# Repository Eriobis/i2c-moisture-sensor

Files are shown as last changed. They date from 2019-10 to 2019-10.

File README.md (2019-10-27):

# i2c-moisture-sensor
BLE Moisture Sensor
Based on Miceuz's work 
 - I2C based soil moisture sensor. A continuation of the [Chirp - plant watering alarm](https://github.com/Miceuz/PlantWateringAlarm) project. There is also an [RS485](https://github.com/Miceuz/rs485-moist-sensor) and an [analog](https://github.com/Miceuz/soil-moisture-sensor-analog) version available.

## BLE advertisement packet
Advertisement data description 

- 2 Bytes - Specific manufacturer data : 0xFFFF ( no manufacturer )
- 4 bytes (float) -> Vcc ( Vbatt )
- 4 bytes (float) -> Sense value
- 4 bytes (float) -> SPARE1
- 4 bytes (float) -> SPARE2

Advertise data example :
``` c
uint8_t adv_data[] = {
    /* Advertising data: Flags AD Type */
    0x02, 
    AD_TYPE_FLAGS,
    FLAG_BIT_LE_GENERAL_DISCOVERABLE_MODE | FLAG_BIT_BR_EDR_NOT_SUPPORTED, 
    0x06,                                 // Len
    AD_TYPE_SHORTENED_LOCAL_NAME,         // Local name
    'S', 'B', 'M', 'S', '1',
    /* Advertising data: manufacturer specific data */
    0x13,                                 // Len ( 19 )
    AD_TYPE_MANUFACTURER_SPECIFIC_DATA,   // manufacturer type
    0xFF, 0xFF,                           // Company identifier code (Default is 0x0030 -
                                          // STMicroelectronics: To be customized for specific identifier)
                                          // FFFF = No identifier
    'D', 'A', 'T', 'A',                   // Vcc in float
    'D', 'A', 'T', 'A',                   // Sense value
    'D', 'A', 'T', 'A',
    'D', 'A', 'T', 'A',
};
```

## Debug adaptor

A ST-LinkV2 can be used to program the chip.

The connector is based on the J-Link 9 pins pinout. 
https://www.segger.com/products/debug-probes/j-link/accessories/adapters/9-pin-cortex-m-adapter/

## Code

At this moment, this repo is only for the HW design, the code is in another repo.

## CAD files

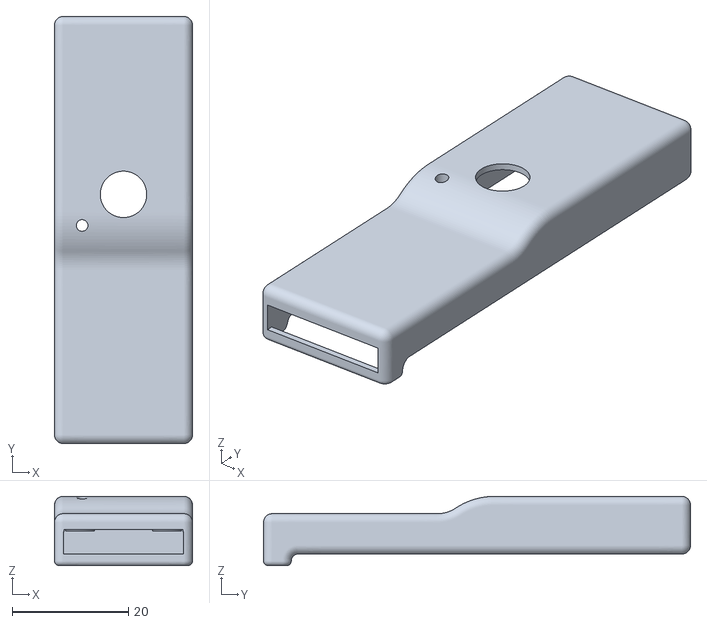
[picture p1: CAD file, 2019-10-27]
Housing/Proto/BodyV2.stl
23.8 x 73.6 x 11.9

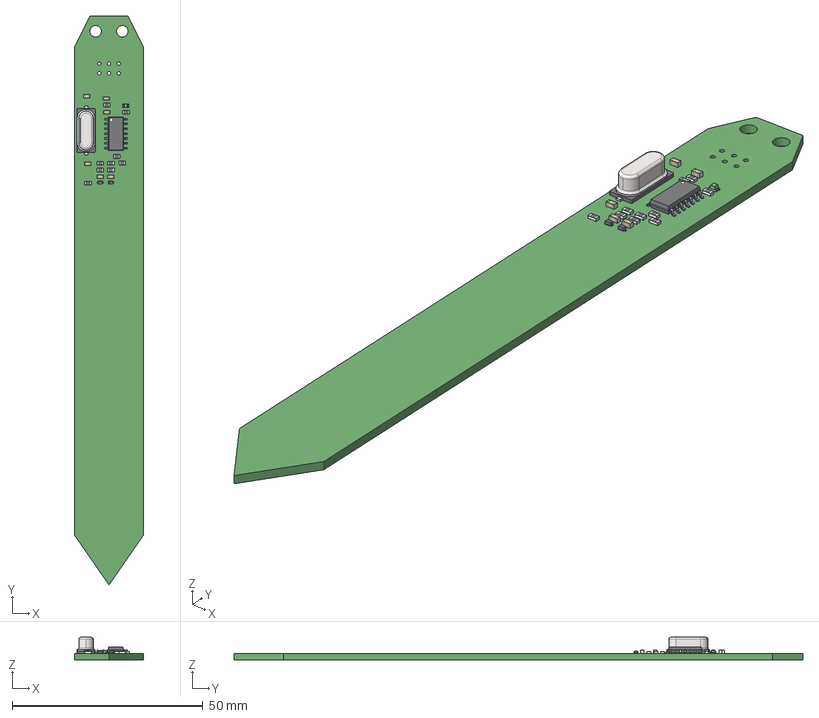
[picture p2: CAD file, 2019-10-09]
i2c-moist-sensor.stp
18.0 x 149.0 x 5.90 mm

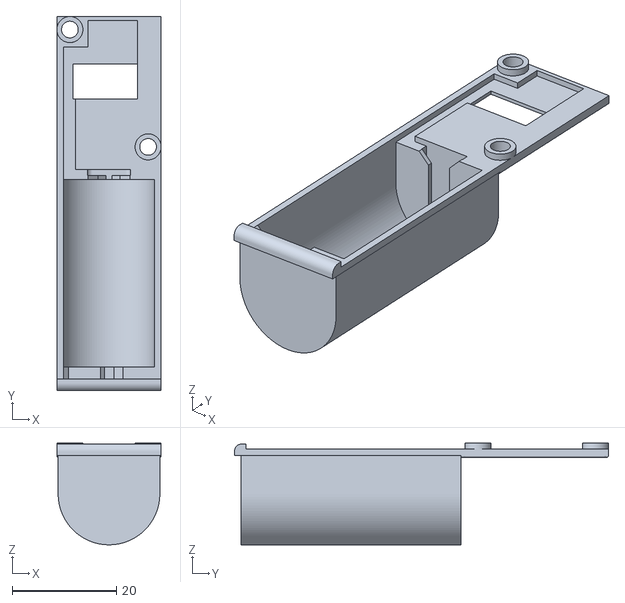
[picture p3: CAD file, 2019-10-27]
Housing/Proto/BattHolderV3.stl
20.0 x 71.7 x 19.5

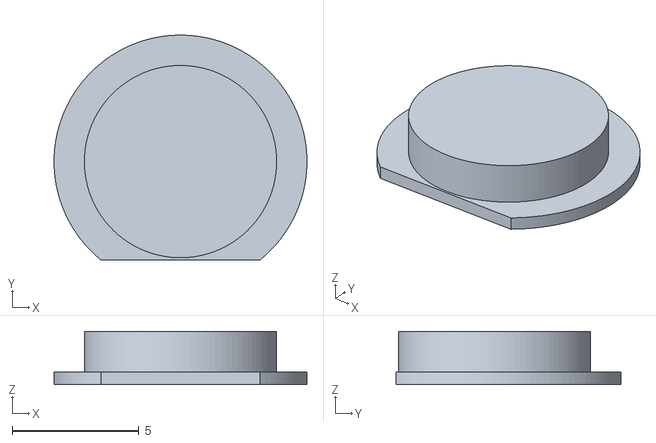
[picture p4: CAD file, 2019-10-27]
Housing/Proto/Button_V1.stl
10.00 x 8.89 x 2.10

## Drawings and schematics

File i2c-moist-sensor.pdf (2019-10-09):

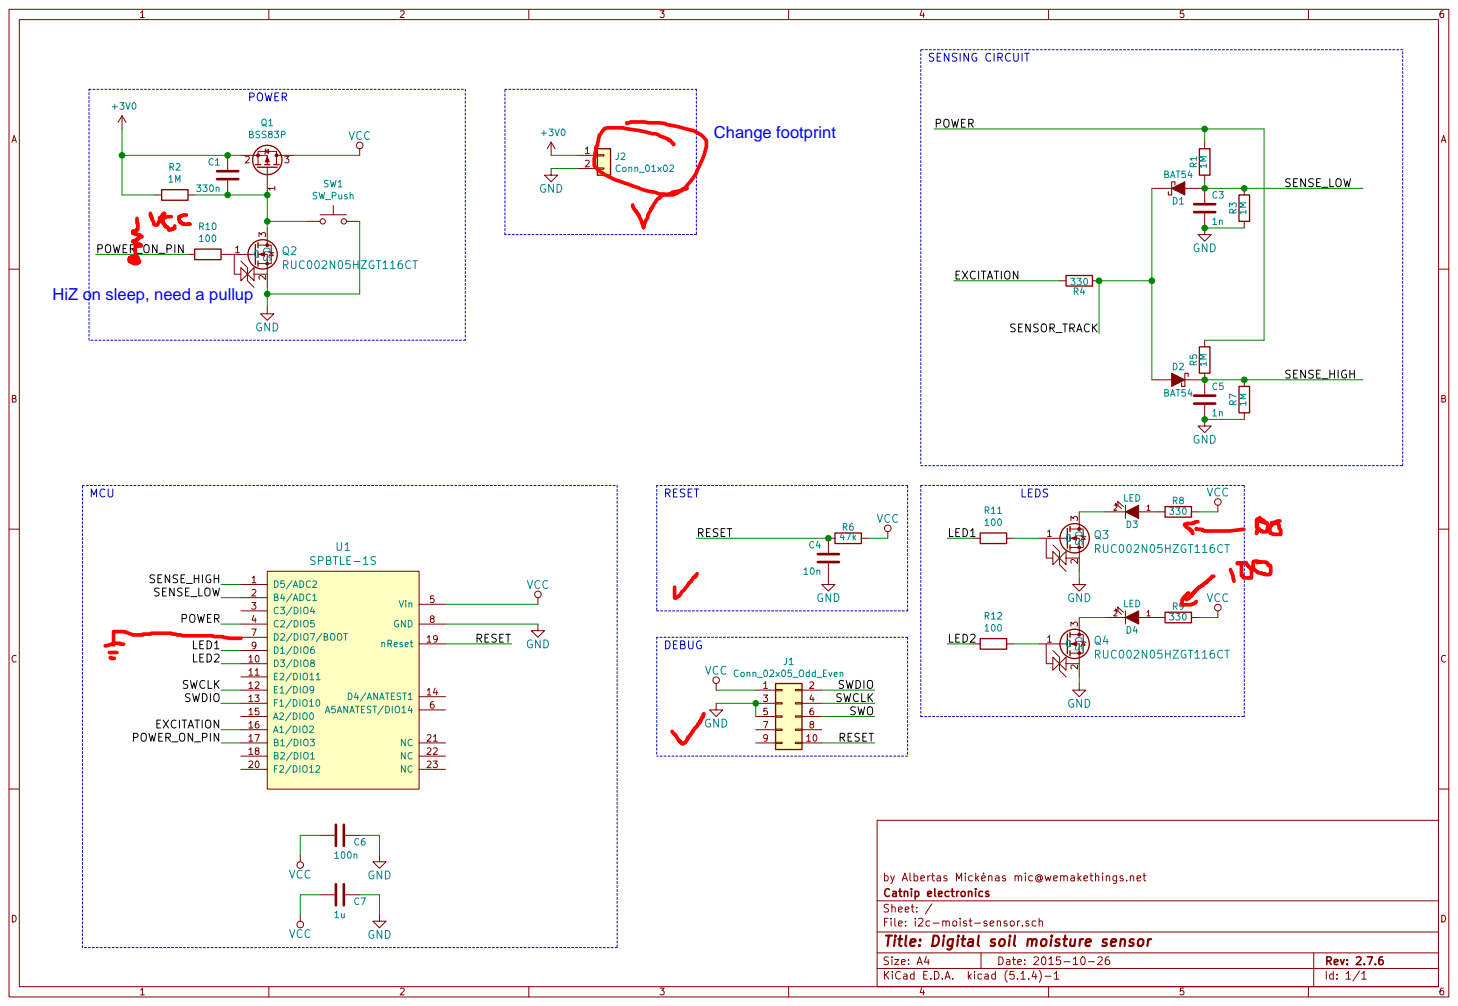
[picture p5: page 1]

Id: 1/1 Title: Digital soil moisture sensor File: i2c-moist-sensor.sch Sheet: / Catnip electronics

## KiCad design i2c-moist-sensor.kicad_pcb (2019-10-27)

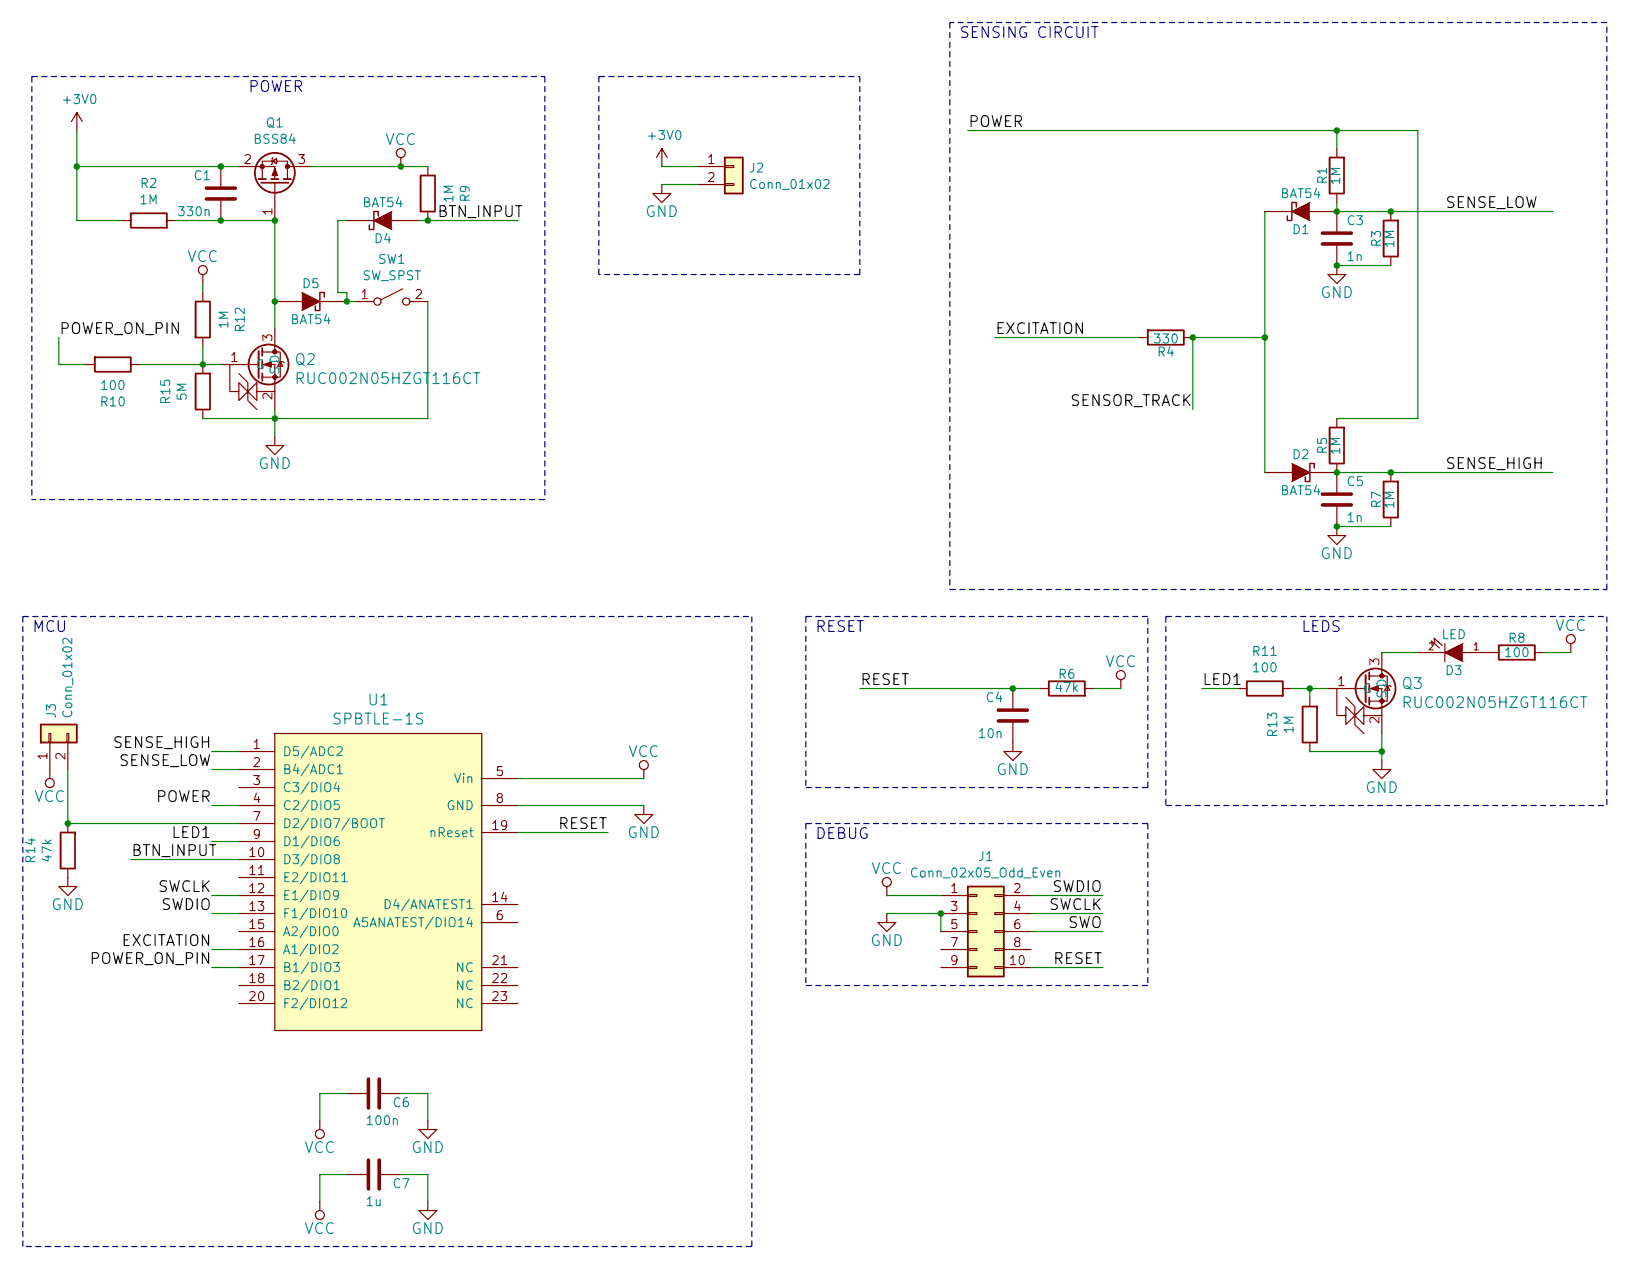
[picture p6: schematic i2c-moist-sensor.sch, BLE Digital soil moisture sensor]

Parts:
C1: 330n; C_0603_HandSoldering; PartNo MC0603X105K100CT
C3, C5: 1n; C_0603_HandSoldering; PartNo MC0603B102K500CT
C4: 10n; C_0603_HandSoldering; PartNo MC0603X105K100CT
C6: 100n; C_0603_HandSoldering; PartNo MC0603X105K100CT
C7: 1u; C_0603_HandSoldering; PartNo MC0603X105K100CT
D1, D2, D4, D5: BAT54; D_SOD-523; PartNo BAT54XV2
D3: LED; LED_0603_HandSoldering; PartNo KP-1608SURCK
J1: Conn_02x05_Odd_Even; 50mils_JTAG
J2, J3: Conn_01x02; Pin_Header_Straight_1x02_Pitch2.54mm
Q1: BSS84; SOT-23_Handsoldering
Q2, Q3: RUC002N05HZGT116CT; SOT-23_Handsoldering
R1, R3, R5, R7: 1M; R_0603_HandSoldering; PartNo MCWR06X1004FTL
R2, R9, R12, R13: 1M; R_0603_HandSoldering
R4: 330; R_0603_HandSoldering; PartNo MCWR06X3300FTL
R6: 47k; R_0603_HandSoldering; PartNo ERJ3RBD1002V
R8: 100; R_0603_HandSoldering; PartNo MCWR06X3300FTL
R10, R11: 100; R_0603_HandSoldering
R14: 47k; R_0603_HandSoldering
R15: 5M; R_0603_HandSoldering
SW1: SW_SPST; TL3305AF160QG
U1: SPBTLE-1S; SPBTLE-1s

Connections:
+3V0: C1.1, J2.1, Q1.2 (S), R2.1
/BTN_INPUT: D4.1 (A), R9.2, U1.10 (D3/DIO8)
/EXCITATION: R4.2, U1.16 (A1/DIO2)
/LED1: R11.1, U1.9 (D1/DIO6)
/POWER: R1.2, R5.2, U1.4 (C2/DIO5)
/POWER_ON_PIN: R10.2, U1.17 (B1/DIO3)
/RESET: C4.1, J1.10, R6.1, U1.19 (nReset)
/SENSE_HIGH: C5.1, D2.2 (K), R5.1, R7.2, U1.1 (D5/ADC2)
/SENSE_LOW: C3.1, D1.1 (A), R1.1, R3.2, U1.2 (B4/ADC1)
/SENSOR_TRACK: D1.2 (K), D2.1 (A), R4.1
/SWCLK: J1.4, U1.12 (E1/DIO9)
/SWDIO: J1.2, U1.13 (F1/DIO10)
GND: C3.2, C4.2, C5.2, C6.1, C7.1, J1.3, J1.5, J2.2, Q2.2 (S), Q3.2 (S), R3.1, R7.1, R13.1, R14.1, R15.1, SW1.2 (B), U1.8 (GND)
unnamed: C1.2, D5.1 (A), Q1.1 (G), Q2.3 (D), R2.2
unnamed: D3.1 (A), R8.1
unnamed: D3.2 (K), Q3.3 (D)
unnamed: D4.2 (K), D5.2 (K), SW1.1 (A)
unnamed: J3.2, R14.2, U1.7 (D2/DIO7/BOOT)
unnamed: Q2.1 (G), R10.1, R12.2, R15.2
unnamed: Q3.1 (G), R11.2, R13.2
VCC: C6.2, C7.2, J1.1, J3.1, Q1.3 (D), R6.2, R8.2, R9.1, R12.1, U1.5 (Vin)

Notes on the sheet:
DEBUG
LEDS
RESET
POWER
SENSING CIRCUIT
MCU

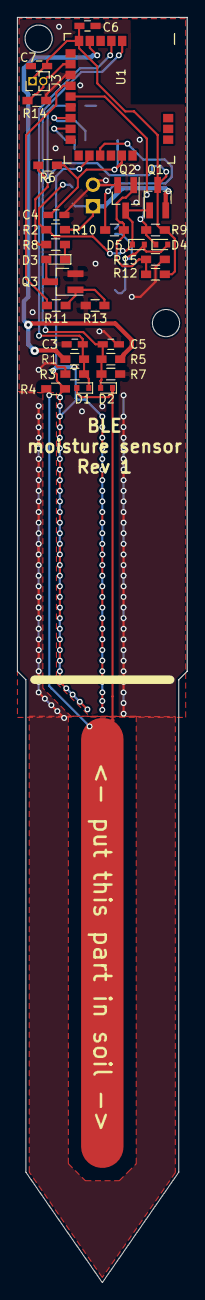
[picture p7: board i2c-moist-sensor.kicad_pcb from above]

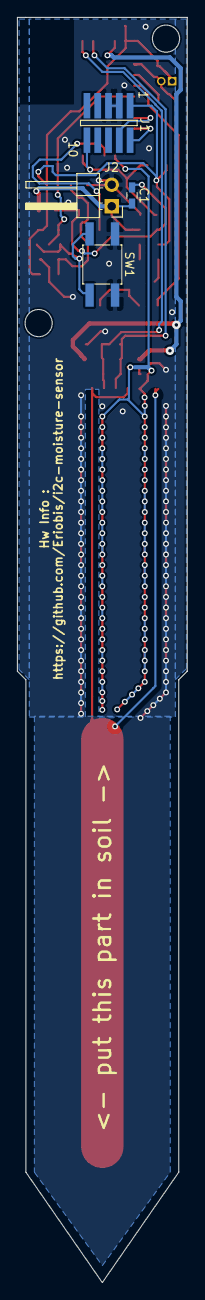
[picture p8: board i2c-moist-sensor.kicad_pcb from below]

Board: 2 copper layers, 20.0 x 149.0 mm, 34 parts (4 on the bottom side), 21 nets.

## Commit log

2019-09-14 SPBTLE version 1.0 - HW
    Only hardware changes
    [i2c-moist-sensor-pannel-B.Cu.gbr, i2c-moist-sensor-pannel-B.Mask.gbr, i2c-moist-sensor-pannel-B.SilkS.gbr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]
2019-10-09 Update files for proto version 1.0
    [i2c-moist-sensor-pannel.kicad_pcb, i2c-moist-sensor.kicad_pcb, i2c-moist-sensor.sch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]
2019-10-09 Add gerber BLE 1.0
    [i2c-moist-sensor-B_Cu.gbr, i2c-moist-sensor-B_Mask.gbr, i2c-moist-sensor-B_Paste.gbr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]
2019-10-27 Updated to Rev1
    - Naming from 1.0 to Rev version number
    - Added pull up for vcc latch
    - Added button input
    - Removed led2
    - Added BOOT pin jumper and pullup
    [BattHolderV3.stl, BodyV2.stl, Button_V1.stl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]
